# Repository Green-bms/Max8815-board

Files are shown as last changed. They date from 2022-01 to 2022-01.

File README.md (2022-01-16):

# Max8815-board


Step-up converter based on MAX8815.

The circuit has the following features:

Input: 1.5V - 5V

Output: 5V fixed or 3.3V - 5V (adjustable).

The max output current depends on input voltage.
the board goes into protection when the input current exceeds 1A

Project web page:
https://hackaday.io/project/183512-max8815-step-up-converter

## Instructions

5V FIXED OUTPUT:

1) Set J3 shunt to "OFF" position
2) Set J4 shunt to "Normal" position
3) Set J5 shunt to "5v" position
4) Connect Input power supply (range 1,5v - 5v)
5) Set J3 shunt to "ON" position
6) Check D1 led lights ON
7) Connect the output load



ADJUSTABLE OUTPUT:
1) Set J3 shunt to "OFF" position
2) Set J4 shunt to "Normal" position
3) Set J5 shunt to "Adj" position
4) Connect Input power supply (range 1,5v - 5v)
5) Set J3 shunt to "ON" position
6) Check D1 led lights ON
7) Set the output voltage (from 3,3v to 5v)  by RV1 potentiometer



By J4 shunt it is possible to set "FPWM" mode according to MAX8815 data sheet

## Open Source Development Applications

The project was created using the following Open source applications:
- **KiCad** 

## Open Source Hardware Certification
Max8815-board has been certified as open source hardware by the Open Source Hardware Association, with the UID: IT000008.

Certificate link: (https://certification.oshwa.org/it000008.html)

## License

This work is licensed under a **Creative Commons Attribution-ShareAlike 4.0 International License**.
https://creativecommons.org/licenses/by-sa/4.0/

### You are free to:

**Share** — copy and redistribute the material in any medium or format

**Adapt**  — remix, transform, and build upon the material
for any purpose, even commercially.
This license is acceptable for Free Cultural Works.
The licensor cannot revoke these freedoms as long as you follow the license terms.

### Under the following terms:

**Attribution** — You must give appropriate credit, provide a link to the license, and indicate if changes were made. You may do so in any reasonable manner, but not in any way that suggests the licensor endorses you or your use.

**ShareAlike** — If you remix, transform, or build upon the material, you must distribute your contributions under the same license as the original.

**No additional restrictions** — You may not apply legal terms or technological measures that legally restrict others from doing anything the license permits.

### Notices:
You do not have to comply with the license for elements of the material in the public domain or where your use is permitted by an applicable exception or limitation.
No warranties are given. The license may not give you all of the permissions necessary for your intended use. For example, other rights such as publicity, privacy, or moral rights may limit how you use the material.

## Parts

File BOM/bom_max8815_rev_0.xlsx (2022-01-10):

 |  |  | bom_max8815_rev0
Item # | *Ref Des | *Qty | Manufacturer | *Mfg Part # | Description / Value | *Package | Type | Your Instructions / Notes
1 | R4 | 1 |  |  | 330 | R_0402_1005Metric | smd | standard smd 0402 resistor
2 | D1 | 1 |  |  | LED | LED_0402_1005Metric | smd | standard smd 0402 led
3 | L1 | 1 | Bourns | SRN4018TA-1R2M | 1.2uH | L_Bourns-SRN4018 | smd
4 | R1 | 1 |  |  | 510k | R_0402_1005Metric | smd | standard smd 0402 led
5 | C3 | 1 |  |  | 100nF | C_0402_1005Metric | smd | standard smd 0402 capacitor
6 | C2 | 1 | Murata | ECASD41E226M040KA0 | 22uF 10V | CP_EIA-7343-20 | smd
7 | C1 | 1 | Taiyo Yuden | JMK212BJ106KG | 10uF 6,3V | C_0805_2012Metric | smd
8 | U1 | 1 | Maxim Integrated | MAX8815AETB+ | MAX8815AETB+ | 10 TDFN-EP | smd
9 | R3 | 1 |  |  | 100 | R_0402_1005Metric | smd | standard smd 0402 resistor
10 | R2 | 1 |  |  | 330k | R_0402_1005Metric | smd | standard smd 0402 resistor

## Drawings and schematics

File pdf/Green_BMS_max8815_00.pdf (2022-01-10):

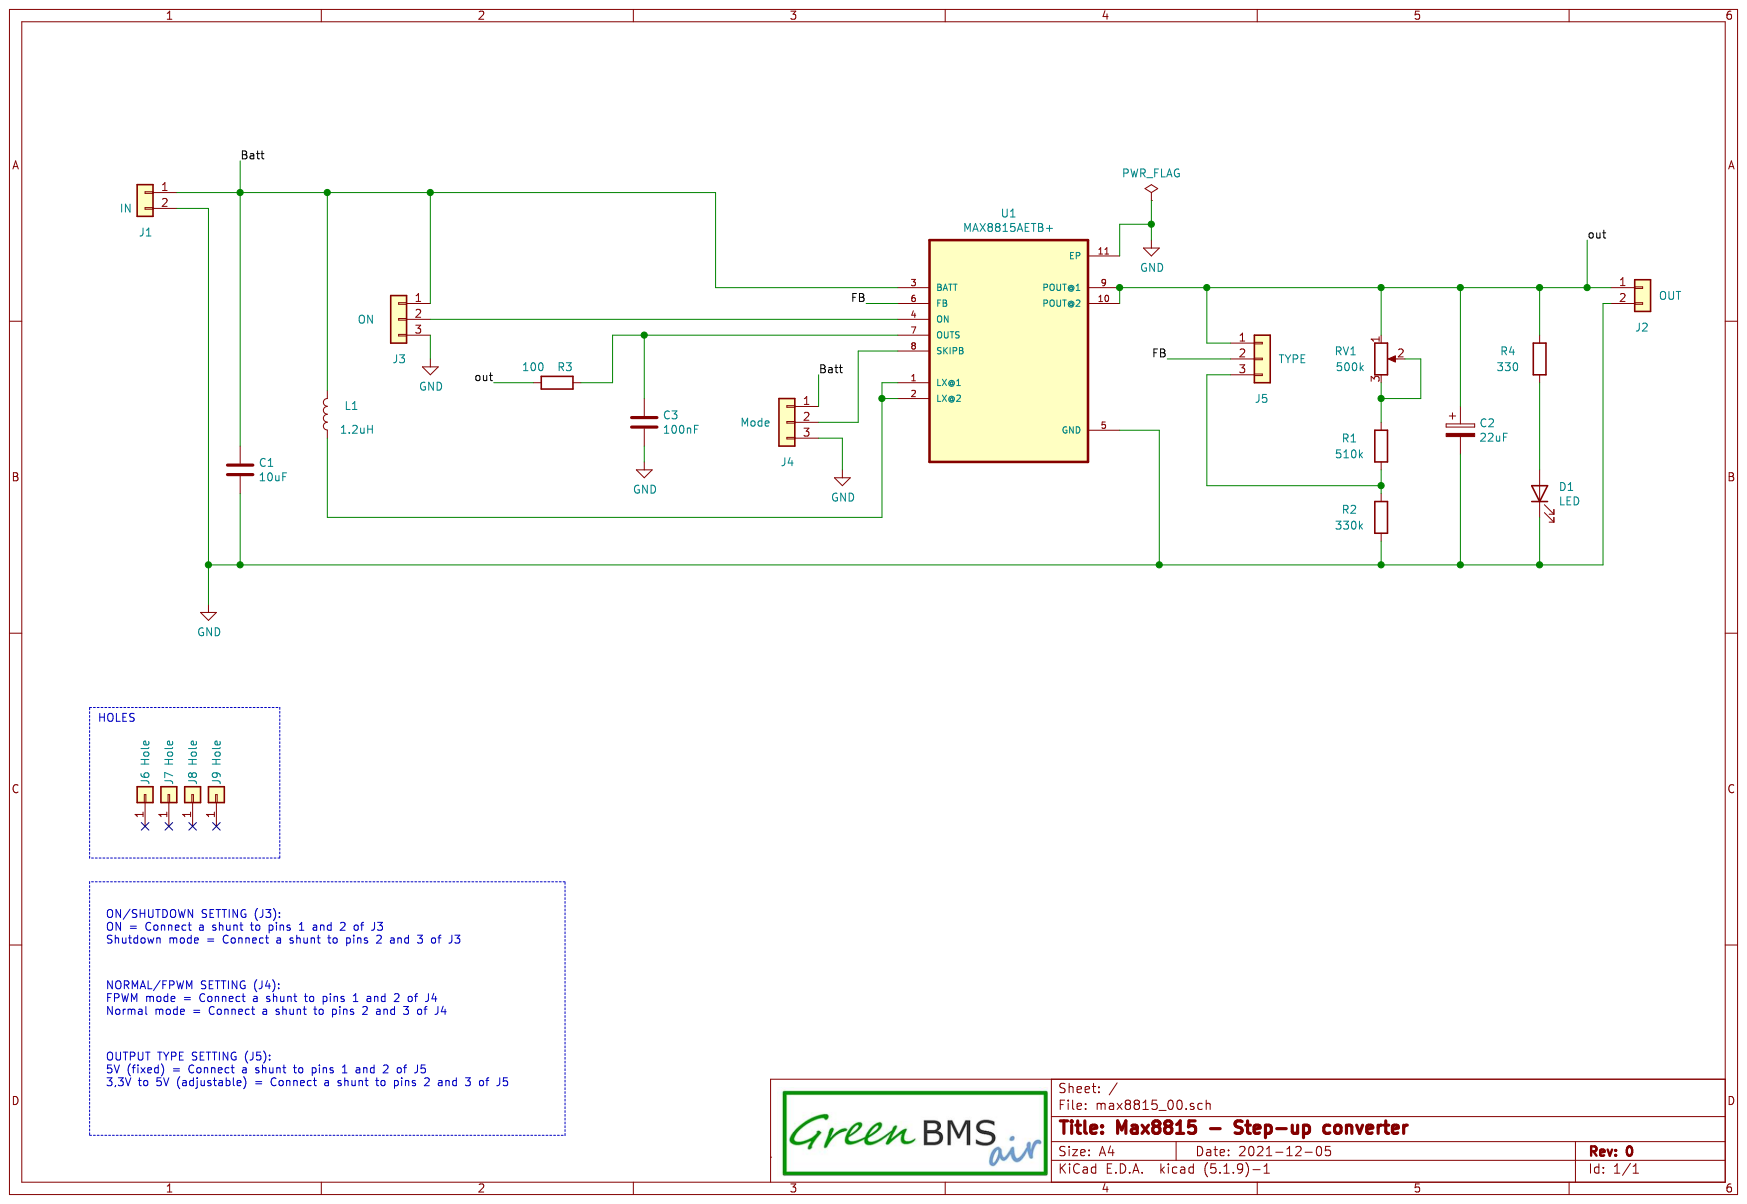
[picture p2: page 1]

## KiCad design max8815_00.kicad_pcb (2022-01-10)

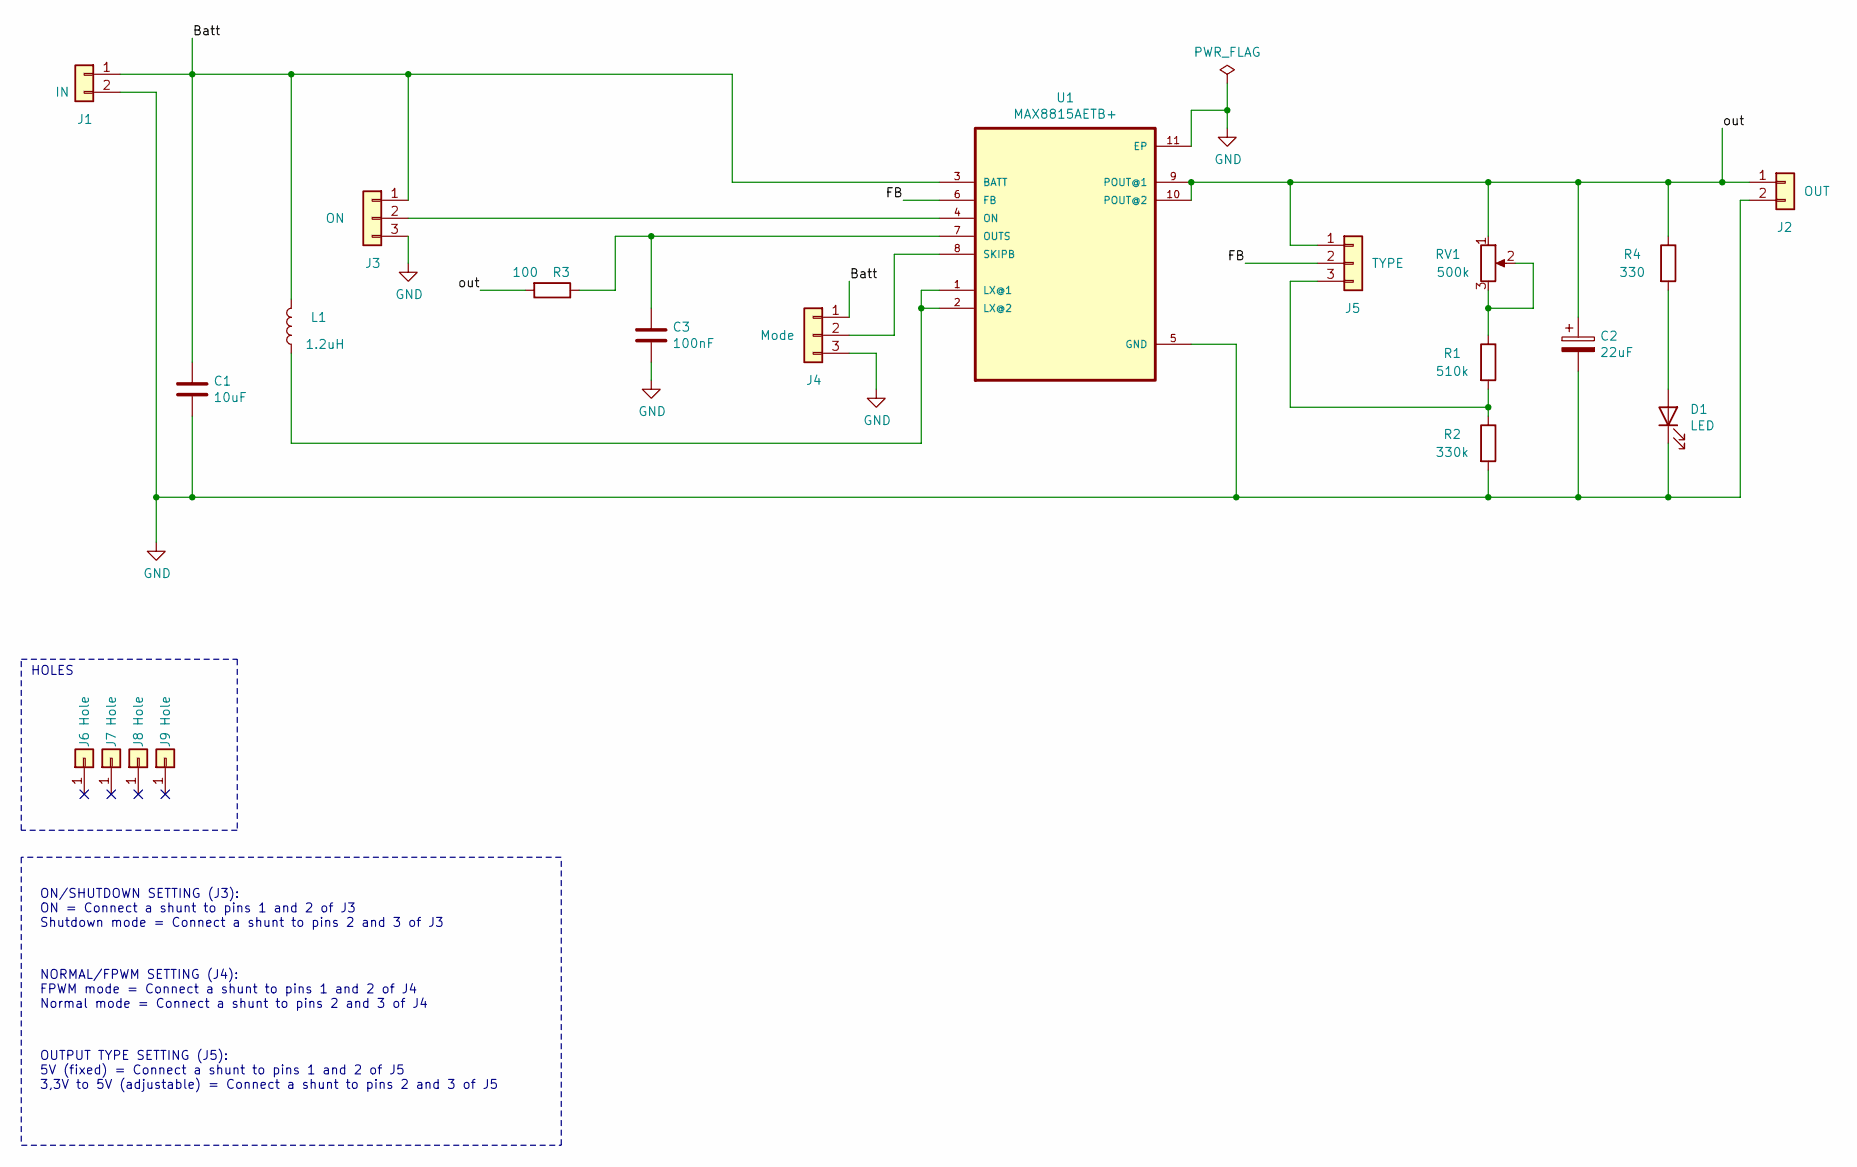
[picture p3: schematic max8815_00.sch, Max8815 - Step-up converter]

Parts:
C1: 10uF; C_0805_2012Metric
C2: 22uF; CP_EIA-7343-20_Kemet-V
C3: 100nF; C_0402_1005Metric
D1: LED; LED_0402_1005Metric
J1: IN; PinHeader_1x02_P2.54mm_Vertical
J2: OUT; PinHeader_1x02_P2.54mm_Vertical
J3: ON; PinHeader_1x03_P2.54mm_Vertical
J4: Mode; PinHeader_1x03_P2.54mm_Vertical
J5: TYPE; PinHeader_1x03_P2.54mm_Vertical
J6, J7, J8, J9: Hole; MountingHole_3.2mm_M3
L1: 1.2uH; L_Bourns-SRN4018
R1: 510k; R_0402_1005Metric
R2: 330k; R_0402_1005Metric
R3: 100; R_0402_1005Metric
R4: 330; R_0402_1005Metric
RV1: 500k; Potentiometer_Bourns_3296W_Vertical
U1: MAX8815AETB+; DFN300X300X80-11N

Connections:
/Batt: C1.1, J1.1, J3.1, J4.1, L1.2, U1.3 (BATT); also elsewhere on the board
/FB: J5.2, U1.6 (FB)
/out: C2.1, J2.1, J5.1, R3.2, R4.1, RV1.1, U1.9 (POUT@1), U1.10 (POUT@2); also elsewhere on the board
GND: C1.2, C2.2, C3.2, D1.1 (K), J1.2, J2.2, J3.3, J4.3, R2.2, U1.5 (GND), U1.11 (EP); also elsewhere on the board
unnamed: C3.1, R3.1, U1.7 (OUTS)
unnamed: D1.2 (A), R4.2
unnamed: J3.2, U1.4 (ON)
unnamed: J4.2, U1.8 (SKIPB)
unnamed: J5.3, R1.2, R2.1
unnamed: L1.1, U1.1 (LX@1), U1.2 (LX@2)
unnamed: R1.1, RV1.2, RV1.3

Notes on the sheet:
ON/SHUTDOWN SETTING (J3): ON = Connect a shunt to pins 1 and 2 of J3 Shutdown mode = Connect a shunt to pins 2 and 3 of J3
NORMAL/FPWM SETTING (J4): FPWM mode = Connect a shunt to pins 1 and 2 of J4 Normal mode = Connect a shunt to pins 2 and 3 of J4
OUTPUT TYPE SETTING (J5): 5V (fixed) = Connect a shunt to pins 1 and 2 of J5 3,3V to 5V (adjustable) = Connect a shunt to pins 2 and 3 of J5
HOLES

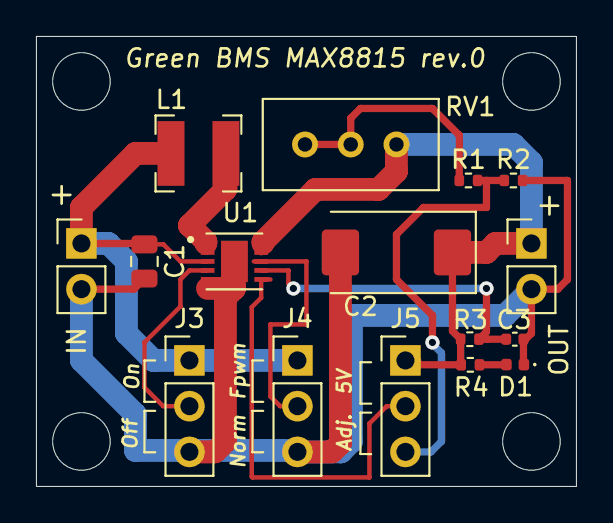
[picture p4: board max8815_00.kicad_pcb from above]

Board: 2 copper layers, 30.0 x 25.0 mm, 20 parts (0 on the bottom side), 11 nets.

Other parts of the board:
IN: IN; PinHeader_1x02_P2.54mm_Vertical
OUT: OUT; PinHeader_1x02_P2.54mm_Vertical

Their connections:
/Batt: IN.1; also elsewhere on the board
/out: OUT.1; also elsewhere on the board
GND: IN.2, OUT.2; also elsewhere on the board
